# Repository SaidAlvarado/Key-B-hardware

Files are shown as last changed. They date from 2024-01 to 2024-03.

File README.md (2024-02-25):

# Key-B keyboard
ZMK based wireless half keyboard

Remember to attribute: https://github.com/daprice/keyswitches.pretty/tree/master

Attribute the Fanstel module footprint and symbols to: https://github.com/hemalchevli/Fanstel-kicad-library

## Battery
- [Big Option](https://www.amazon.fr/EEMB-Batterie-polym%C3%A8re-Rechargeable-connecteur/dp/B09DPPP8ZV/)
  - JST Connector (PH). [Digikey Link](https://www.amazon.fr/EEMB-Batterie-polym%C3%A8re-Rechargeable-connecteur/dp/B09DPPP8ZV/?th=1)
- [Slightly smaller option](https://www.amazon.fr/EEMB-Batterie-Rechargeable-Navigation-Enregistreur/dp/B08FD3V6TF)
- Charging current
  - std 0.2C, max. 1C. (60mA to 300mA)

## BOM

- Premade digikey cart: https://www.digikey.fr/short/4dtv58d8

## References

#### Crystal oscillator design
- [General nRF crystal design guidelines](https://devzone.nordicsemi.com/guides/hardware-design-test-and-measuring/b/nrf5x/posts/general-pcb-design-guidelines-for-nrf52)
- [nRF52840 reference circuit](https://infocenter.nordicsemi.com/index.jsp?topic=%2Fps_nrf52840%2Fref_circuitry.html)
  - They recommend a 9pF crystal for the 32.768kHz crystal
- [Nordic White paper on Crystal oscillator design](https://infocenter.nordicsemi.com/pdf/nwp_015.pdf?cp=12_12) Note, there is a correction of this white paper on the first link in this section.

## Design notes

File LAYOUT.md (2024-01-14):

# Keyboard Layout

Based on Colemak-Mod-DH
We use 3 thumb buttons for layer shifts.
- **Flip:** for the right-side alpha keys
- **Num:** for the number and arrow keys
- **Symb:** for other symbols

I don't know what to use the other thumb buttons for. I guess volume, bluetooth and macros for Blender? 

<p align="center">
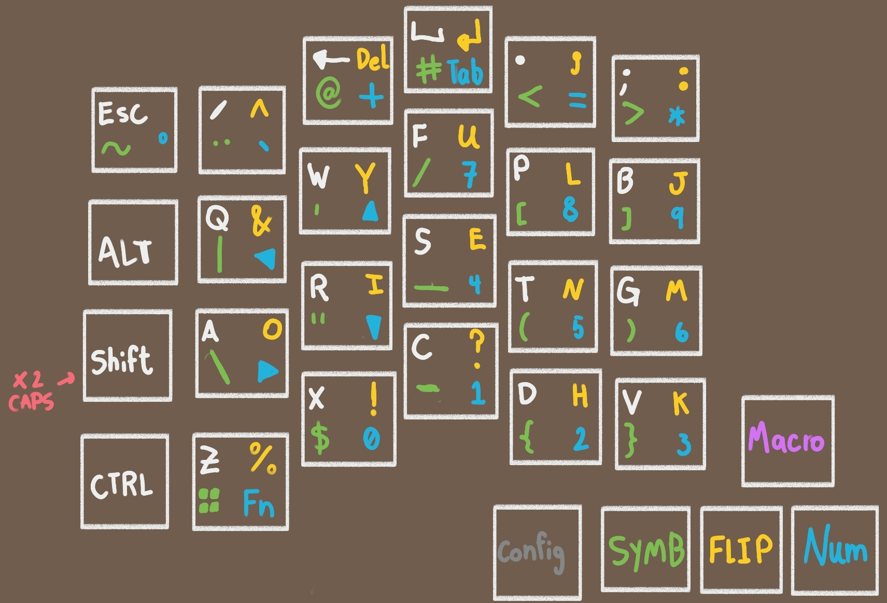
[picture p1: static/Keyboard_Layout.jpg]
Keyboard Layout
  
</p>

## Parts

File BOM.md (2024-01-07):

# Bill of Material

Here is a full breakdown of the components cost for this project. 
Prices are in USD.
Prices are the price of an individual component, in low quantities.

**Total price of all the components: $86.16**

## PCB Components

Premade Digikey cart: [https://www.digikey.fr/short/4dtv58d8](https://www.digikey.fr/short/4dtv58d8)

| Reference | Value | Digikey Link | Price | Qty |
|:---|:---|:---|---:|---:|
| C1 | 100 nF | [https://www.digikey.fr/short/dfdcwqzh](https://www.digikey.fr/short/dfdcwqzh) | 0.1  | 1 |
| C2-C4 | 4.7 uF | [https://www.digikey.fr/short/9ddcdmj1](https://www.digikey.fr/short/9ddcdmj1) | 0.12 | 3 |
| C5, C6 | 12pF | [https://www.digikey.fr/short/93345tjz](https://www.digikey.fr/short/93345tjz) | 0.1  | 2 |
| D1 | STS321050B100 | [https://www.digikey.fr/short/ndftbf2d](https://www.digikey.fr/short/ndftbf2d) | 0.37 | 1 |
| F1 | ERB-RE0R75V | [https://www.digikey.fr/short/8chdpvvc](https://www.digikey.fr/short/8chdpvvc) | 0.27 | 1 |
| J1 | USB4510-03-1-A | [https://www.digikey.fr/short/t5517rjb](https://www.digikey.fr/short/t5517rjb) | 0.8  | 1 |
| J2 | Battery | [https://www.digikey.fr/short/4nfzf328](https://www.digikey.fr/short/4nfzf328) | 0.17 | 1 |
| L1, L2 | BLM18SG121TN1D | [https://www.digikey.fr/short/5017v0dz](https://www.digikey.fr/short/5017v0dz) | 0.13 | 2 |
| LED1 | orange | [https://www.digikey.fr/short/wn1w0bhr](https://www.digikey.fr/short/wn1w0bhr) | 0.24 | 1 |
| LED2 | green | [https://www.digikey.fr/short/9hh0d35q](https://www.digikey.fr/short/9hh0d35q) | 0.19 | 1 |
| Q1 | 2N7002 | [https://www.digikey.fr/short/2whmm8p2](https://www.digikey.fr/short/2whmm8p2) | 0.45 | 1 |
| R1 | 1 MOhm | [https://www.digikey.fr/short/z45v3mjc](https://www.digikey.fr/short/z45v3mjc) | 0.1  | 1 |
| R2, R3 | 5.1 kOhm | [https://www.digikey.fr/short/n44t24n9](https://www.digikey.fr/short/n44t24n9) | 0.1  | 2 |
| R4 | 47 kOhm | [https://www.digikey.fr/short/92pntfd4](https://www.digikey.fr/short/92pntfd4) | 0.1  | 1 |
| R5, R8 | 1.5 kOhm | [https://www.digikey.fr/short/phch2hb9](https://www.digikey.fr/short/phch2hb9) | 0.1  | 2 |
| R6 | 5.6 kOhm | [https://www.digikey.fr/short/d7m30hjz](https://www.digikey.fr/short/d7m30hjz) | 0.1  | 1 |
| R7, R10 | 10 kOhm | [https://www.digikey.fr/short/q2w0pb82](https://www.digikey.fr/short/q2w0pb82) | 0.1  | 2 |
| R9 | 100 Ohm | [https://www.digikey.fr/short/b2zjwm5d](https://www.digikey.fr/short/b2zjwm5d) | 0.1  | 1 |
| R11 | 100 kOhm | [https://www.digikey.fr/short/3j5f0vnv](https://www.digikey.fr/short/3j5f0vnv) | 0.1  | 1 |
| R12 | 470 Ohm | [https://www.digikey.fr/short/jp814v51](https://www.digikey.fr/short/jp814v51) | 0.1  | 1 |
| SW1 | PWR | [https://www.digikey.fr/short/pnt4qtt1](https://www.digikey.fr/short/pnt4qtt1) | 1.07 | 1 |
| SW2 | Reset | [https://www.digikey.fr/short/qt5jdm9z](https://www.digikey.fr/short/qt5jdm9z) | 0.75 | 1 |
| U1 | SRV05-4 | [https://www.digikey.fr/short/p7hw7bpv](https://www.digikey.fr/short/p7hw7bpv) | 0.1  | 1 |
| U2 | BQ24075 | [https://www.digikey.fr/short/cn0mz24p](https://www.digikey.fr/short/cn0mz24p) | 2.35 | 1 |
| U3 | BT840 | [https://www.digikey.fr/short/4qd39n5h](https://www.digikey.fr/short/4qd39n5h) | 10.94 | 1 |
| Y1 | ECS-.327-9-34B-TR  | [https://www.digikey.fr/short/w4d4tdrt](https://www.digikey.fr/short/w4d4tdrt) | 0.46 | 1 |

**Total price: $ 20.28**

## Keycaps and Switches

| Description | Link | Price | Qty |
|:---|:---|---:|---:|
| Kailh Low Profile Choc Switches (Tactile Brown 50gf) | [Link](https://splitkb.com/collections/switches-and-keycaps/products/kailh-low-profile-choc-switches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) | 0.56  | 29 |
| White 1u keycaps | [Link](https://splitkb.com/collections/switches-and-keycaps/products/moergo-pom-mbk-profile-keycaps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) | 0.5 | 20 |
| Black 1u keycaps | [Link](https://splitkb.com/collections/switches-and-keycaps/products/moergo-pom-mbk-profile-keycaps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) | 0.5  | 4 |
| Red 1u convex keycaps | [Link](https://splitkb.com/collections/switches-and-keycaps/products/mbk-pbt-coloured-blank-keycaps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) | 0.5 | 4 |
| Green 1u conves keycaps | [Link](https://splitkb.com/collections/switches-and-keycaps/products/mbk-pbt-coloured-blank-keycaps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) | 0.5 | 1 |
| Kailh Hotswap Sockets | [Link](https://splitkb.com/products/kailh-hotswap-sockets?variant=43579173306627) | 0.16 | 29 |

**Total price: $ 35.38**

## PCB and Batery

| Description | Link | Price | Qty |
|:---|:---|---:|---:|
| PCB + stencil (from JLCPCB)  | [Link](https://jlcpcb.com/) | ~20  | 1 |
| 300mAh Li-ion Battery | [Link](https://www.amazon.fr/EEMB-Batterie-polym%C3%A8re-Rechargeable-connecteur/dp/B09DPPP8ZV/) | 10.5 | 1 |

**Total price: $ 30.5**

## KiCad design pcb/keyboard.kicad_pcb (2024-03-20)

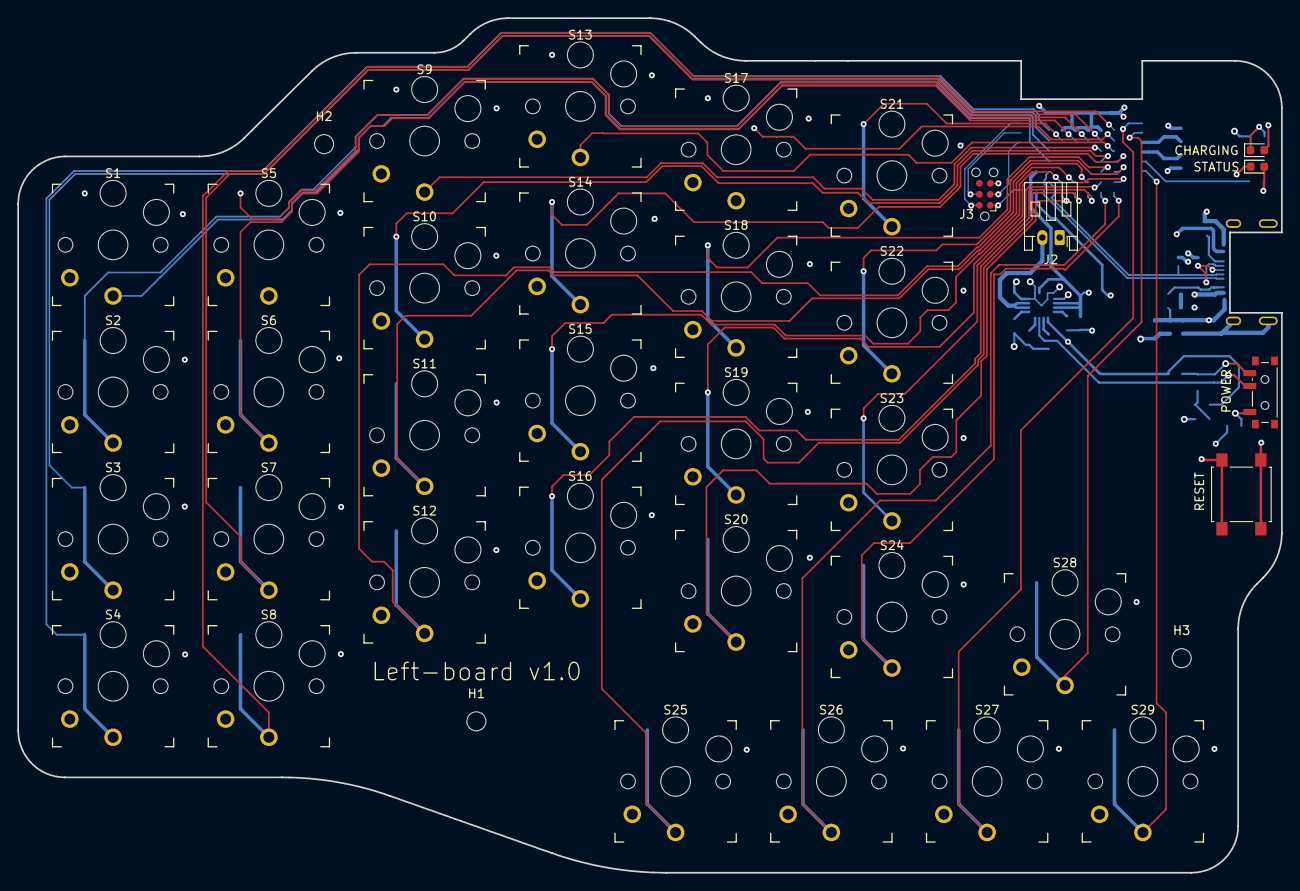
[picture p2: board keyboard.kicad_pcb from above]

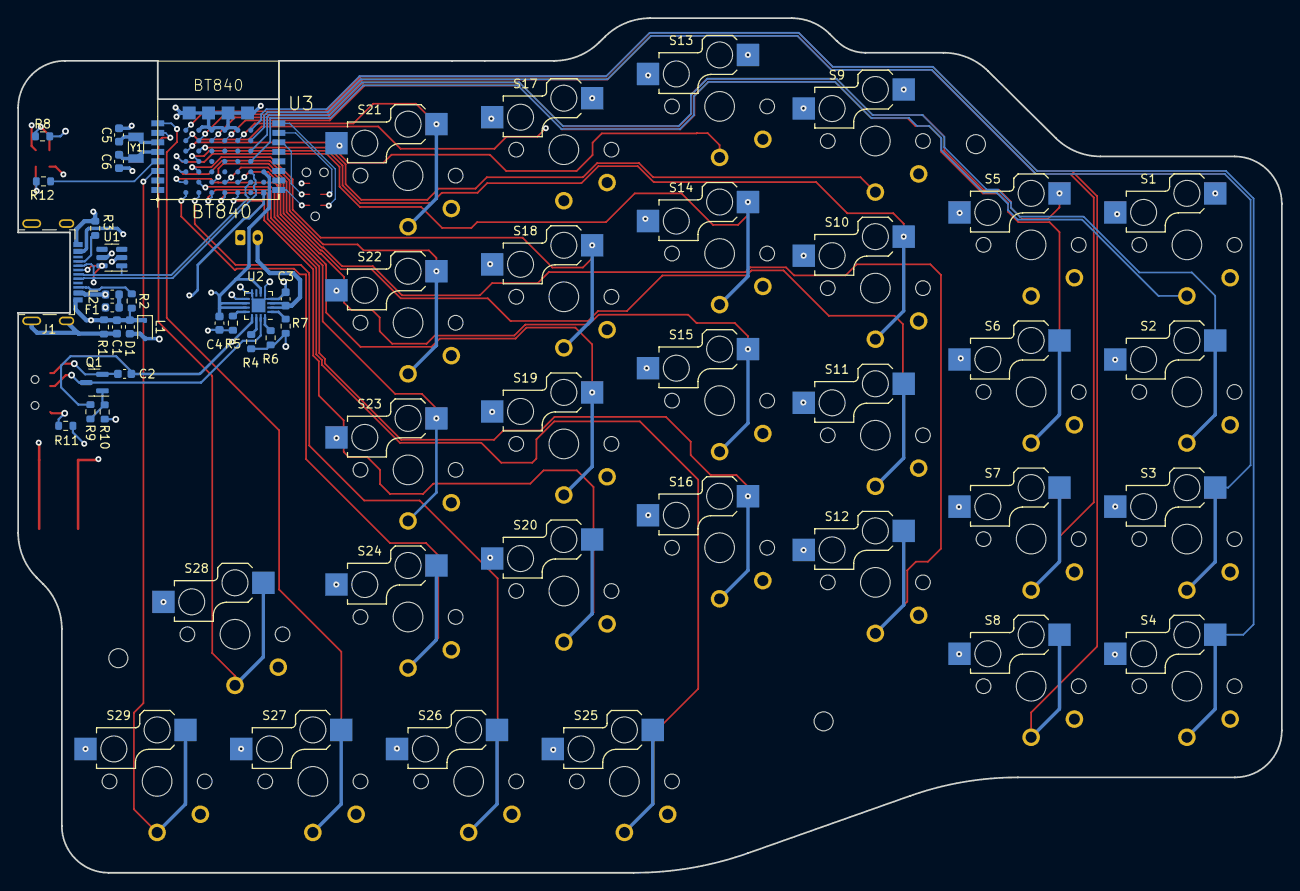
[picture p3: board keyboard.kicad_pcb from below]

Board: 4 copper layers, 146.0 x 98.8 mm, 66 parts (28 on the bottom side), 58 nets.

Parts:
C1: 100 nF; C_0603_1608Metric
C2, C3, C4: 4.7 uF; C_0603_1608Metric
C5, C6: 12pF; C_0603_1608Metric
D1: STS321050B100; D_SOD-323
F1: ERB-RE0R75V; Fuse_0603_1608Metric
H1, H2, H3: MountingHole; MountingHole_2.2mm_M2
J1: USB4510-03-1-A; USB_C_Receptacle_GCT_USB4510-03-1-A
J2: Battery; JST_PH_S2B-PH-K_1x02_P2.00mm_Horizontal
J3: Tag-Connect TC2030; Tag-Connect_TC2030-IDC-NL_2x03_P1.27mm_Vertical
L1, L2: BLM18SG121TN1D; L_0603_1608Metric
LED1: orange; LED_0603_1608Metric
LED2: green; LED_0603_1608Metric
Q1: 2N7002; SOT-23
R1: 1 MOhm; R_0603_1608Metric
R2, R3: 5.1 kOhm; R_0603_1608Metric
R4: 47 kOhm; R_0603_1608Metric
R5, R8: 1.5 kOhm; R_0603_1608Metric
R6: 5.6 kOhm; R_0603_1608Metric
R7, R10: 10 kOhm; R_0603_1608Metric
R9: 100 Ohm; R_0603_1608Metric
R11: 100 kOhm; R_0603_1608Metric
R12: 470 Ohm; R_0603_1608Metric
S1, S2, S3, S4, S5, S6, S7, S8, S9, S10, S11, S12, S13, S14, S15, S16, S17, S18, S19, S20, S21, S22, S23, S24, S25, S26, S27, S28, S29: Kailh_socket_PG1350_optional
SW1: PWR; SW_SPDT_PCM12
SW2: Reset; SW_SPST_B3S-1000
U1: SRV05-4; SOT-23-6
U2: BQ24075; VQFN-16-1EP_3x3mm_P0.5mm_EP1.6x1.6mm
U3: BT840; Fanstel_BT840
Y1: ECS-.327-9-34B-TR; Crystal_SMD_3215-2Pin_3.2x1.5mm

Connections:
+5V: C2.1, F1.2, R9.1, U1.5 (VP), U2.13 (IN), U3.F6 (VBUS)
+BATT: C3.1, J2.2, R11.2, U2.2 (BAT), U2.3 (BAT)
+VSW: C4.1, LED1.2 (A), U2.6 (EN1), U2.10 (OUT), U2.11 (OUT), U3.F4 (VDDH)
Earth: C1.2, J1.S1 (SHIELD), R1.1
GND: C2.2, C3.2, C4.2, C5.1, C6.1, D1.2 (A2), J2.1, J3.5, L1.2, LED2.1 (K), Q1.2 (S), R4.2, R5.2, R6.2, R7.2, R10.2, S1.2, S2.2, S3.2, S4.2, S5.2, S6.2, S7.2, S8.2, S9.2, S10.2, S11.2, S12.2, S13.2, S14.2, S15.2, S16.2, S17.2, S18.2, S19.2, S20.2, S21.2, S22.2, S23.2, S24.2, S25.2, S26.2, S27.2, S28.2, S29.2, SW1.3 (C), SW2.2, U1.2 (VN), U2.4 (~CE), U2.5 (EN2), U2.8 (VSS), U2.17 (VSS), U3.A0 (VSS1), U3.B0 (VSS2), U3.C0 (VSS3), U3.D0 (VSS4), U3.F0 (GND), U3.F1 (GND), U3.F2 (GND), U3.F3 (GND)
GNDPWR: C1.1, D1.1 (A1), J1.A1 (GND), J1.A12 (GND), J1.B1 (GND), J1.B12 (GND), L1.1, R1.2, R2.1, R3.1
unnamed: F1.1, L2.2
unnamed: J1.A5 (CC1), R3.2
unnamed: J1.B5 (CC2), R2.2
unnamed: LED1.1 (K), R8.1
unnamed: LED2.2 (A), R12.2
unnamed: Q1.1 (G), R9.2, R10.1
unnamed: R11.1, SW1.1 (A)
unnamed: R5.1, U2.12 (ILIM)
unnamed: R6.1, U2.16 (ISET)
unnamed: R4.1, U2.14 (TMR)
unnamed: R7.1, U2.1 (TS)
unnamed: R8.2, U2.9 (~CHG)
unnamed: C5.2, U3.3 (P0.00/XL1), Y1.2
unnamed: C6.2, U3.4 (P0.01/XL2), Y1.1
unnamed: R12.1, U3.5 (P0.02/AIN0)
P0.03: S29.1, U3.6 (P0.03/AIN1)
P0.04: S10.1, U3.A3 (P0.04)
P0.05: S18.1, U3.A4 (P0.05)
P0.07: S23.1, U3.A5 (P0.07)
P0.08: S12.1, U3.B5 (P0.08)
P0.20: S3.1, U3.E1 (P0.20)
P0.21: S2.1, U3.E2 (P0.21)
P0.23: S21.1, U3.D1 (P0.23)
P0.24: S6.1, U3.C1 (P0.24)
P0.25: S5.1, U3.B1 (P0.25)
P0.26: S27.1, U3.1 (P0.26/SDA)
P0.27: S28.1, U3.2 (P0.27/SCL)
P0.28: S7.1, U3.A1 (P0.28)
P0.29: S9.1, U3.A2 (P0.29)
P1.01: S15.1, U3.D5 (P1.01)
P1.02: S11.1, U3.C5 (P1.02)
P1.03: S16.1, U3.B6 (P1.03)
P1.04: S25.1, U3.C6 (P1.04)
P1.05: S20.1, U3.D6 (P1.05)
P1.06: S24.1, U3.Z6 (P1.06)
P1.07: S4.1, U3.E0 (P1.07)
P1.08: S26.1, U3.A6 (P1.08)
P1.09: S1.1, U3.E3 (P1.09)
P1.10: S19.1, U3.Z5 (P1.10)
P1.11: S8.1, U3.Z0 (P1.11)
P1.12: S17.1, U3.Z1 (P1.12)
P1.13: S13.1, U3.Z2 (P1.13)
P1.14: S14.1, U3.Z3 (P1.14)
P1.15: S22.1, U3.Z4 (P1.15)
RESET: J3.3, SW2.1, U3.14 (P0.18/RESET)
SWDCLK: J3.4, U3.15 (SWCLK)
SWDIO: J3.2, U3.16 (SWDIO)
SYSOFF: Q1.3 (D), SW1.2 (B), U2.15 (SYSOFF)
USB-D+: J1.A6 (D+), J1.B6 (D+), U1.6 (IO4), U3.E4 (D+)
USB-D-: J1.A7 (D-), J1.B7 (D-), U1.1 (IO1), U3.E5 (D-)
VBUS: J1.A4 (VBUS), J1.A9 (VBUS), J1.B4 (VBUS), J1.B9 (VBUS), L2.1
VDD: J3.1, U3.9 (VDD)

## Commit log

2023-12-07 #1 add battery management and USB socket schematics
    [designguide-schematic.kicad_sch, keyboard.kicad_sch]
2023-12-08 #1 add symbol and footprint for BT840
    [keyboard.kicad_sch]
2023-12-08 #1 fix errors on the BT840 symbol and footprint
    [keyboard.kicad_sch]
2023-12-08 #1 Add preliminary switch connections on the schematic
    [keyboard.kicad_sch]
2023-12-11 #1 Change USB connector components to Digikey 0603
    [keyboard.kicad_sch]
2023-12-15 #1 Choose/calculate 32khz crystal. Change all Caps and Res to 0603
    [keyboard.kicad_sch]
2023-12-15 #1 Add crystal circuit design references to the ReadMe
2023-12-16 #1 Select Battery and Battery Connector
    [keyboard.kicad_sch]
2023-12-16 #1 Select power switch
    [keyboard.kicad_sch]
2023-12-16 #1 Select reset switch and LED
    [keyboard.kicad_sch]
2023-12-16 #1 Mark nRF unconnected pins
    [keyboard.kicad_sch]
2023-12-16 #1 Complete BOM information
    [keyboard.kicad_sch]
2023-12-16 #1 Reorganize the schematic
    [keyboard.kicad_sch]
2023-12-16 #1 Reassign component references
    [keyboard.kicad_sch]
2023-12-16 #2 Import schematic components to the PCB
    [keyboard.kicad_pcb]
2023-12-20 #2 add JLCPCB design rules
    [keyboard.kicad_pcb]
2023-12-20 #2 add pcb outline,roughly place components
    [keyboard.kicad_pcb]
2023-12-23 #2 Expand the PCB to accomodate all components
    [keyboard.kicad_pcb, keyboard.kicad_sch]
2023-12-23 #2 route charging circuit, part 1
    [keyboard.kicad_pcb]
2023-12-24 #2 route USB-C connector + diff pair
    [keyboard.kicad_pcb]
2023-12-25 #2 route all the buttons
    [keyboard.kicad_pcb, keyboard.kicad_sch]
2024-01-06 #2 Add mounting holes
    [keyboard.kicad_pcb, keyboard.kicad_sch]
2024-01-06 #2 Add silkscreen names to buttons, leds and version
    [keyboard.kicad_pcb]
2024-01-07 #3 Complete BOM on Kicad schamatic and make digikey cart
    [keyboard.kicad_sch]
2024-01-14 fix: change USB footprint to comply with 0.3mm copper-to-edge constraint
    [keyboard.kicad_pcb]
2024-01-14 Generate gerber files for JLCPCB
    [keyboard-B_Cu.gbl, keyboard-B_Mask.gbs, keyboard-B_Paste.gbp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]
2024-03-01 upgrade project to kicad 8
    [keyboard.kicad_pcb, keyboard.kicad_sch]
2024-03-03 #5 add 3d models for the switches + keycaps
    [keyboard.kicad_pcb]
2024-03-04 #5 link usb connector model to the footprint library
    [keyboard.kicad_pcb]
2024-03-20 #5 Add model for reset button
    [keyboard.kicad_pcb]
2024-03-20 #5 Add BT840 3D model
    [keyboard.kicad_pcb]
2024-03-20 #5 Add battery charger 3D model
    [keyboard.kicad_pcb]
